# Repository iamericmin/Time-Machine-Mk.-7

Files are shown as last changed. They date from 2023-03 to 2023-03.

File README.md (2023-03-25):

# Time-Machine-Mk.-7
Eagle files for the Time Machine Mk. 7, a DIY digital watch powered by a SAMD21 and an LIR2032 battery.

# Repo map
1. Cutting board: failed projects, simple mockups, etc. that didn't make it to the final product
2. Technical drawings: PDFs of TM7 Rev G, the final production version.
3. TM7 older versions: previous revisions of TM7 I kept just cuz

# This only contains hardware files, I'll be working and uploading software here as well soon!

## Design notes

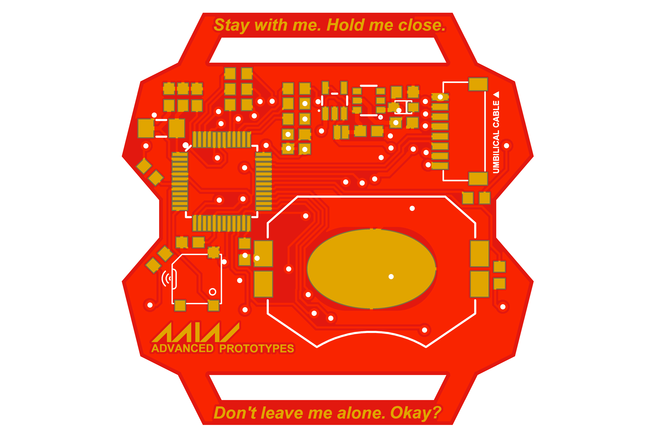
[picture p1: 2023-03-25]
technical drawings/tm7_revG_bottom.png

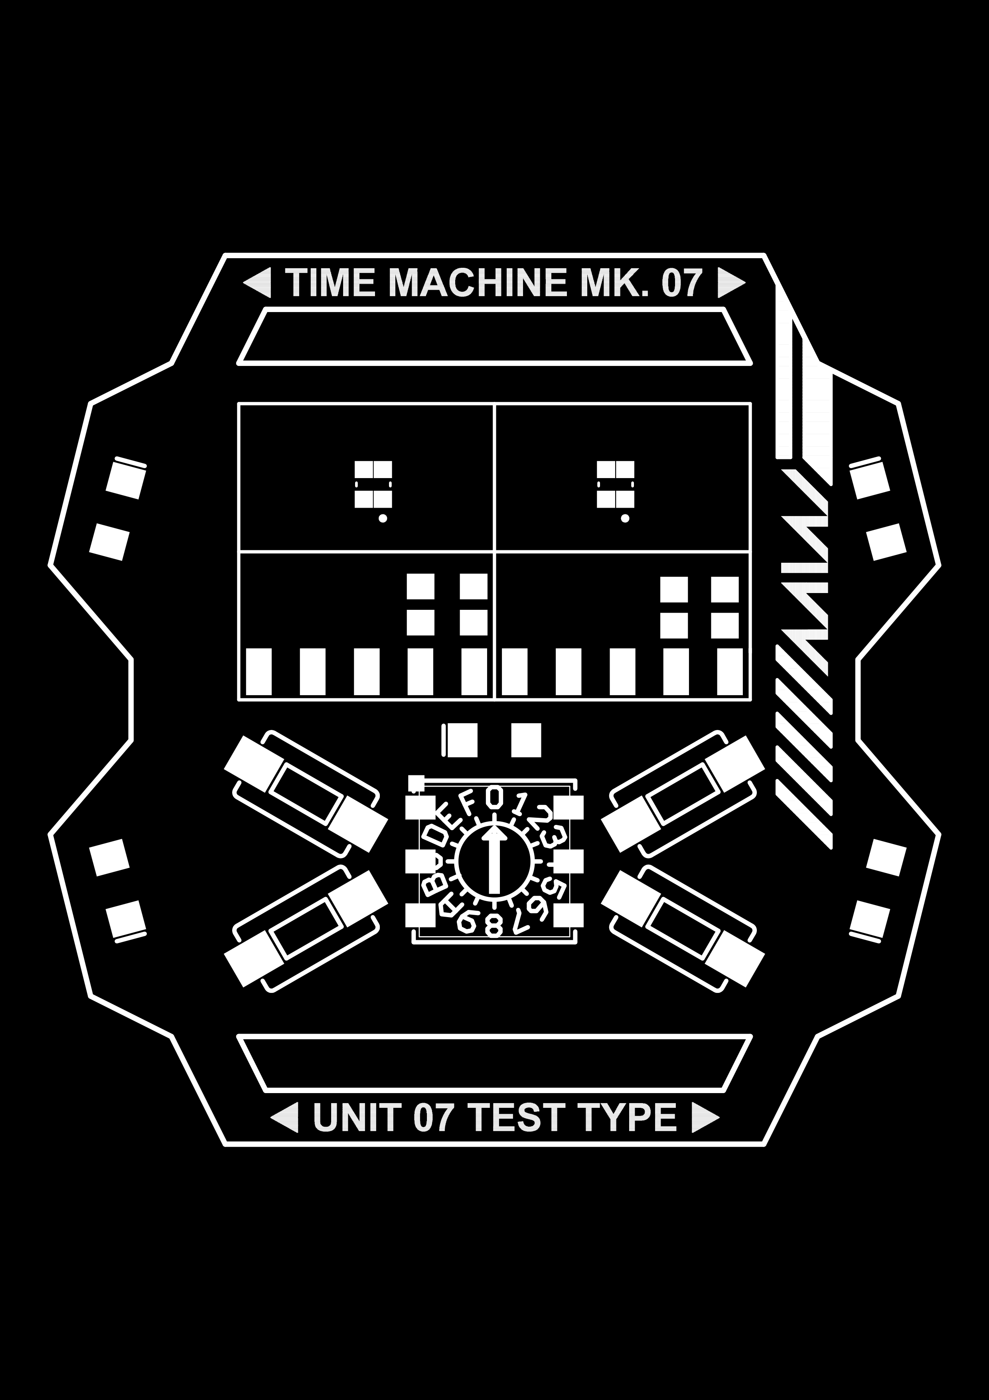
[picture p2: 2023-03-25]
technical drawings/tm7_revG_top_black_inverted.png

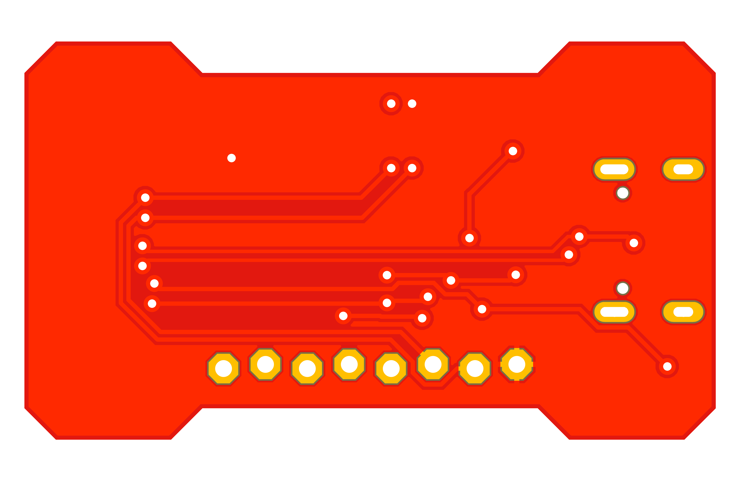
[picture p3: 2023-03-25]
technical drawings/tm7_dock_bottom.png

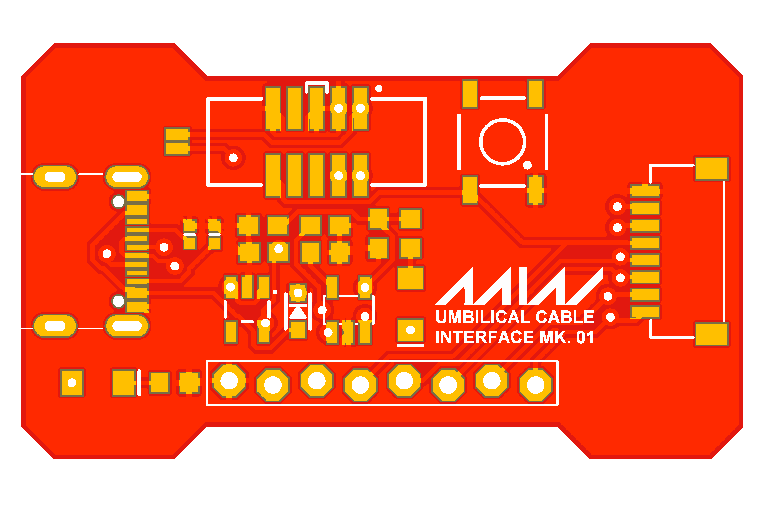
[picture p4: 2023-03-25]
technical drawings/tm7_dock_top.png

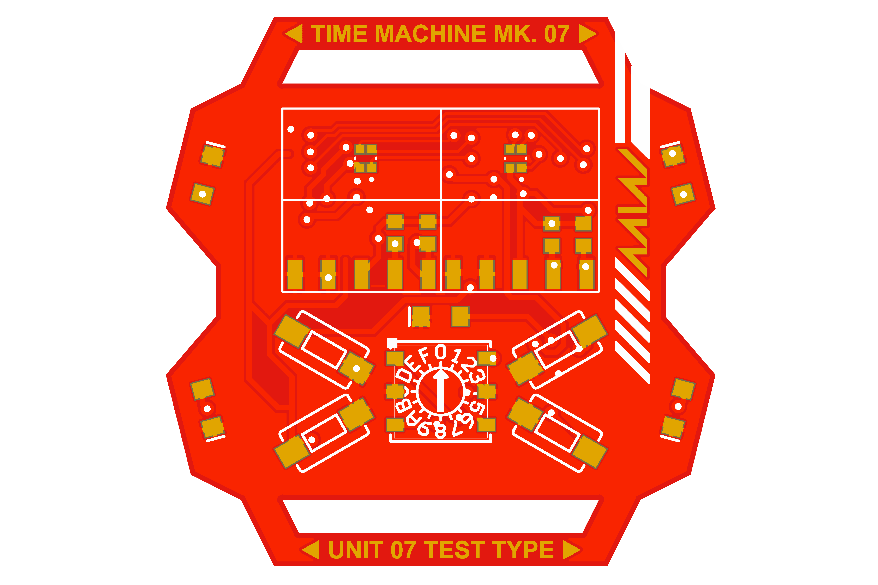
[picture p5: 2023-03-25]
technical drawings/tm7_revG_top.png

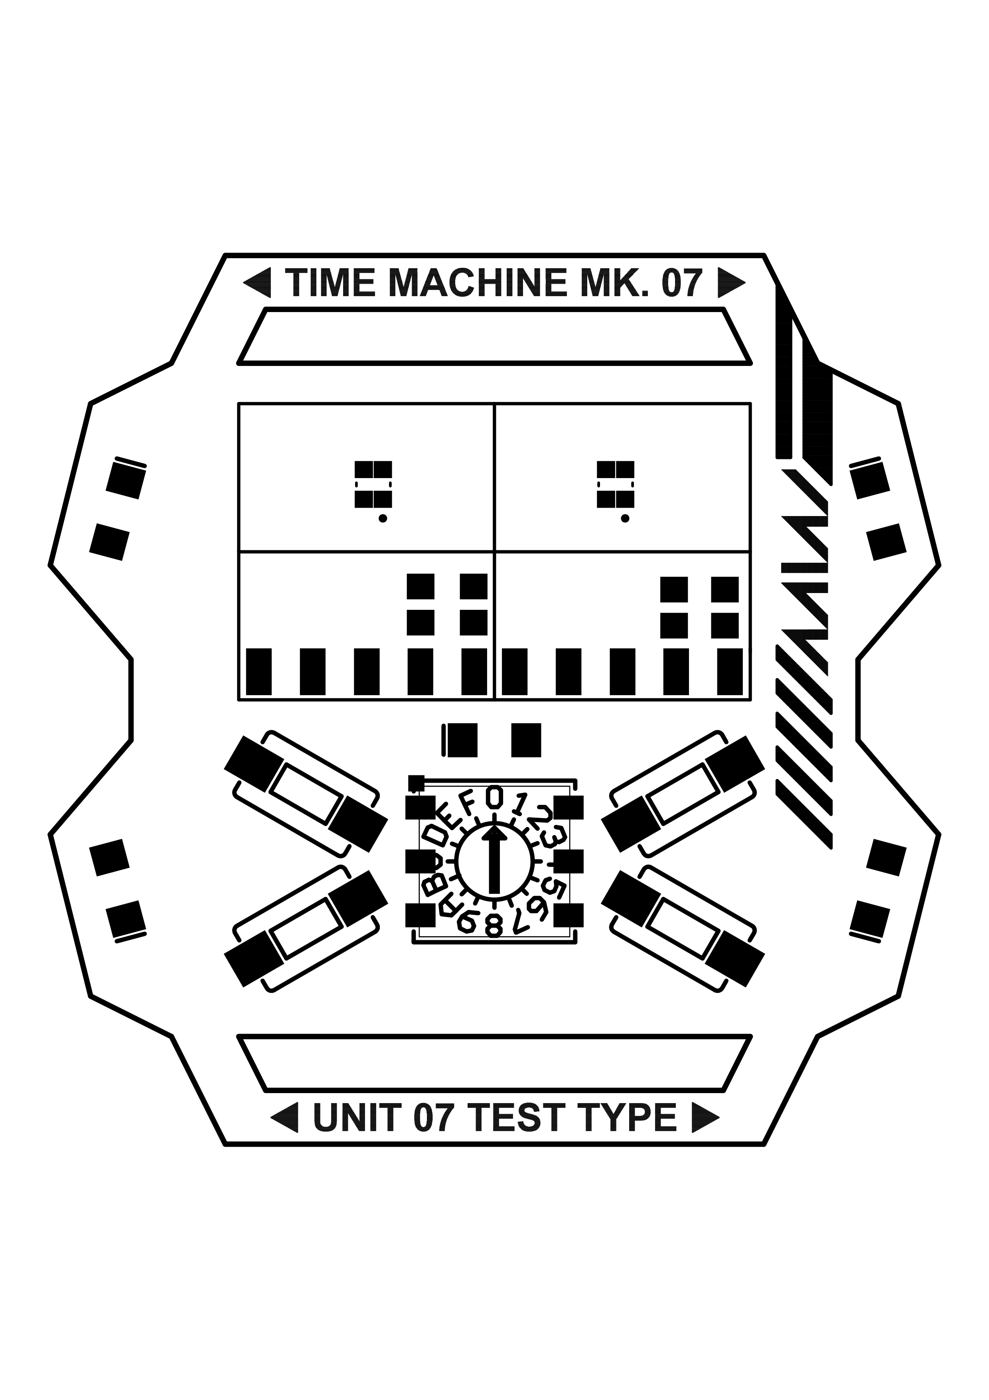
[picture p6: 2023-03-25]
technical drawings/tm7_revG_top_black.png

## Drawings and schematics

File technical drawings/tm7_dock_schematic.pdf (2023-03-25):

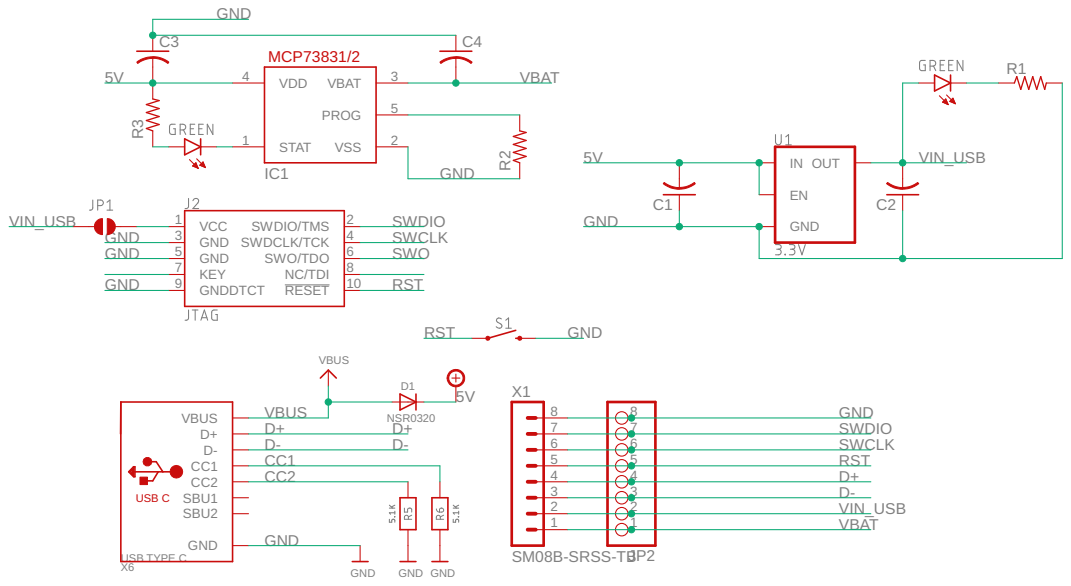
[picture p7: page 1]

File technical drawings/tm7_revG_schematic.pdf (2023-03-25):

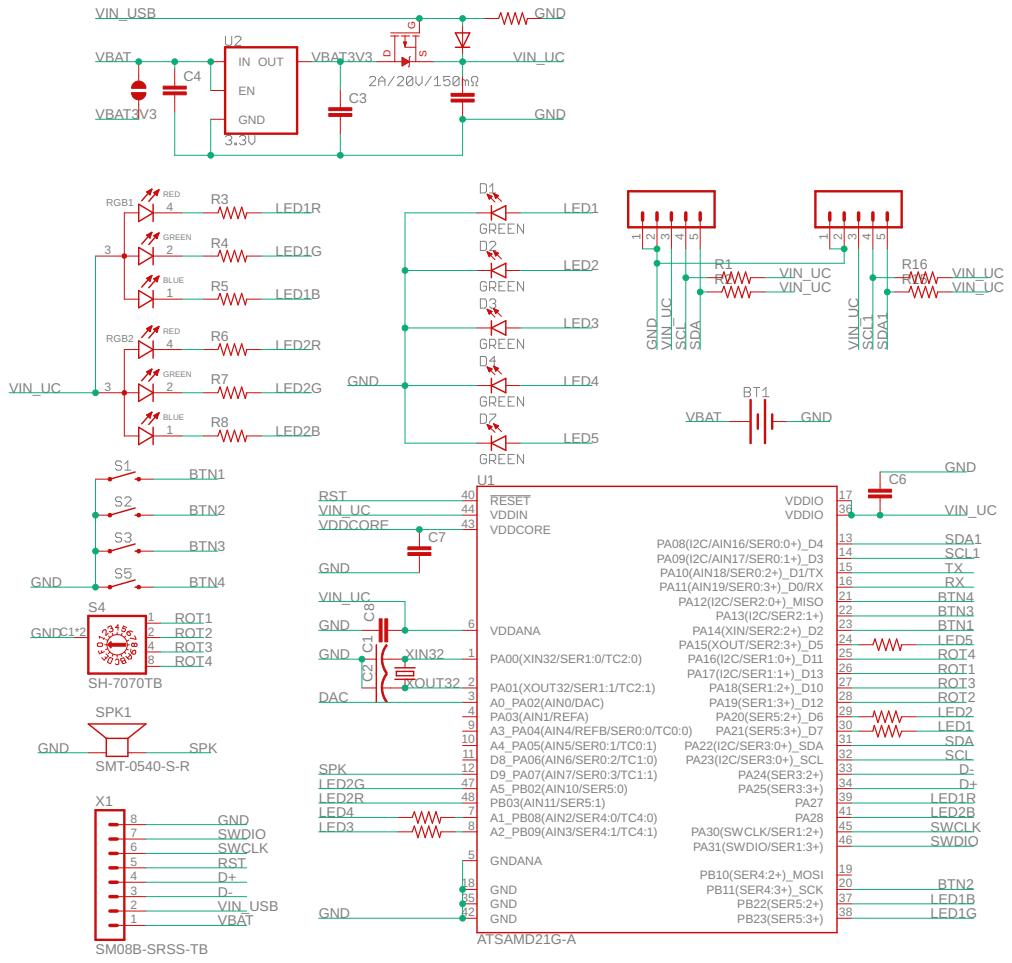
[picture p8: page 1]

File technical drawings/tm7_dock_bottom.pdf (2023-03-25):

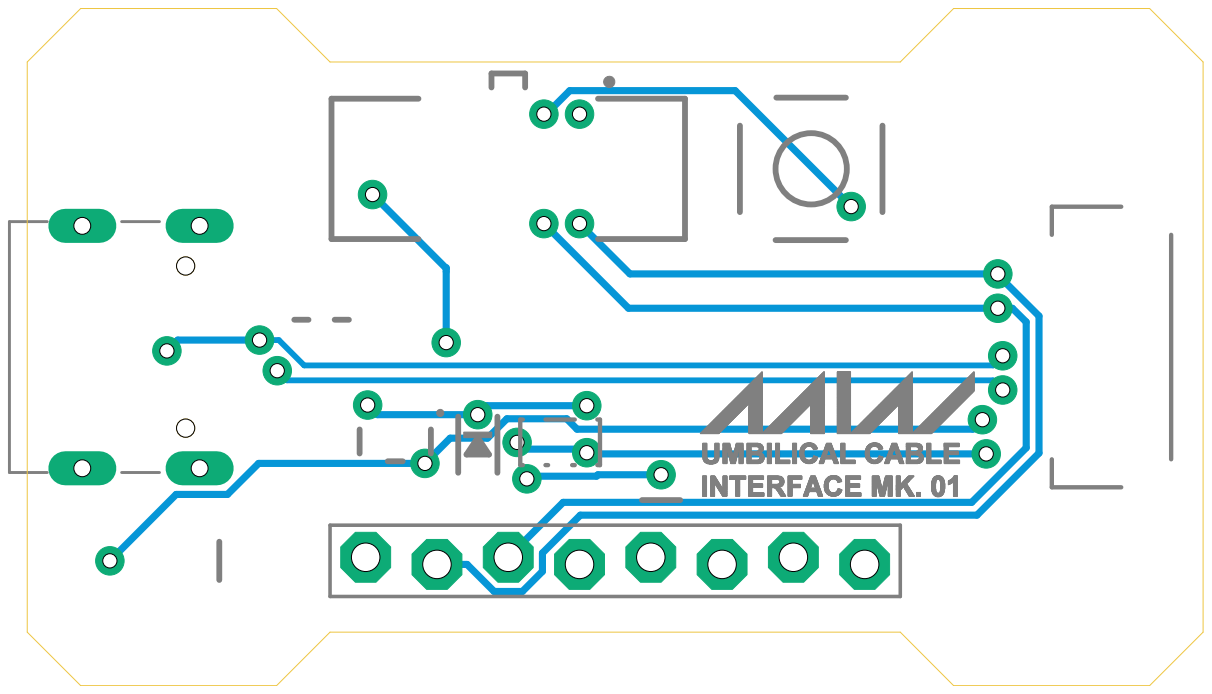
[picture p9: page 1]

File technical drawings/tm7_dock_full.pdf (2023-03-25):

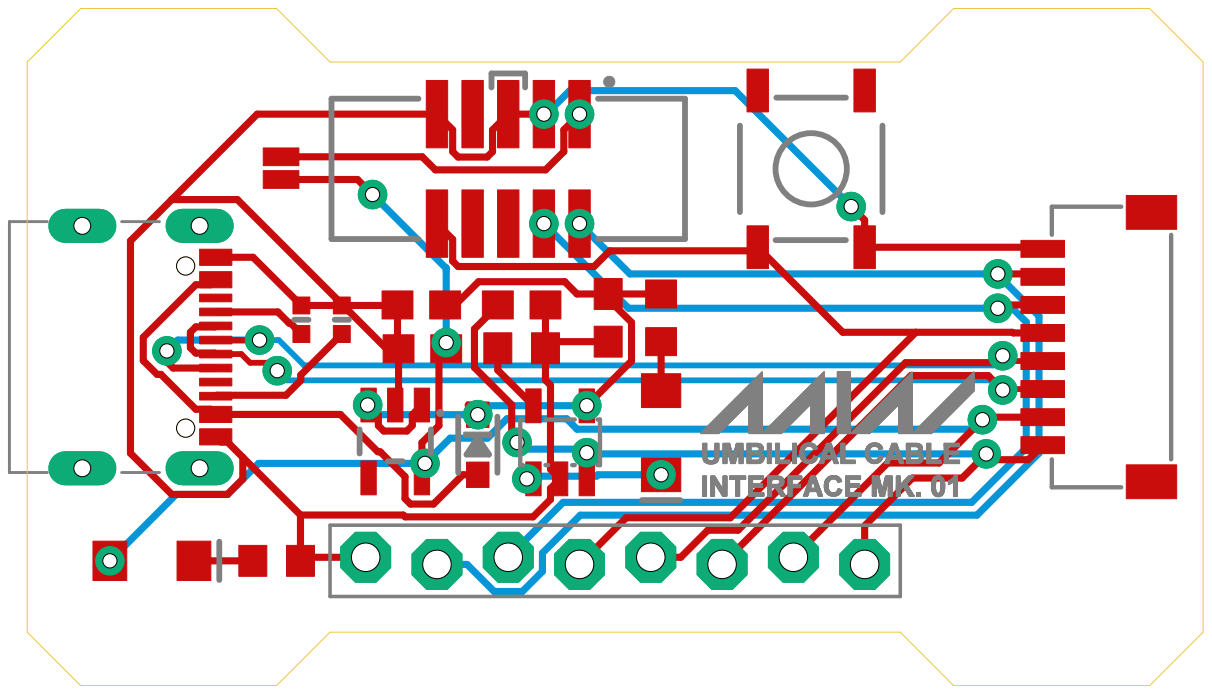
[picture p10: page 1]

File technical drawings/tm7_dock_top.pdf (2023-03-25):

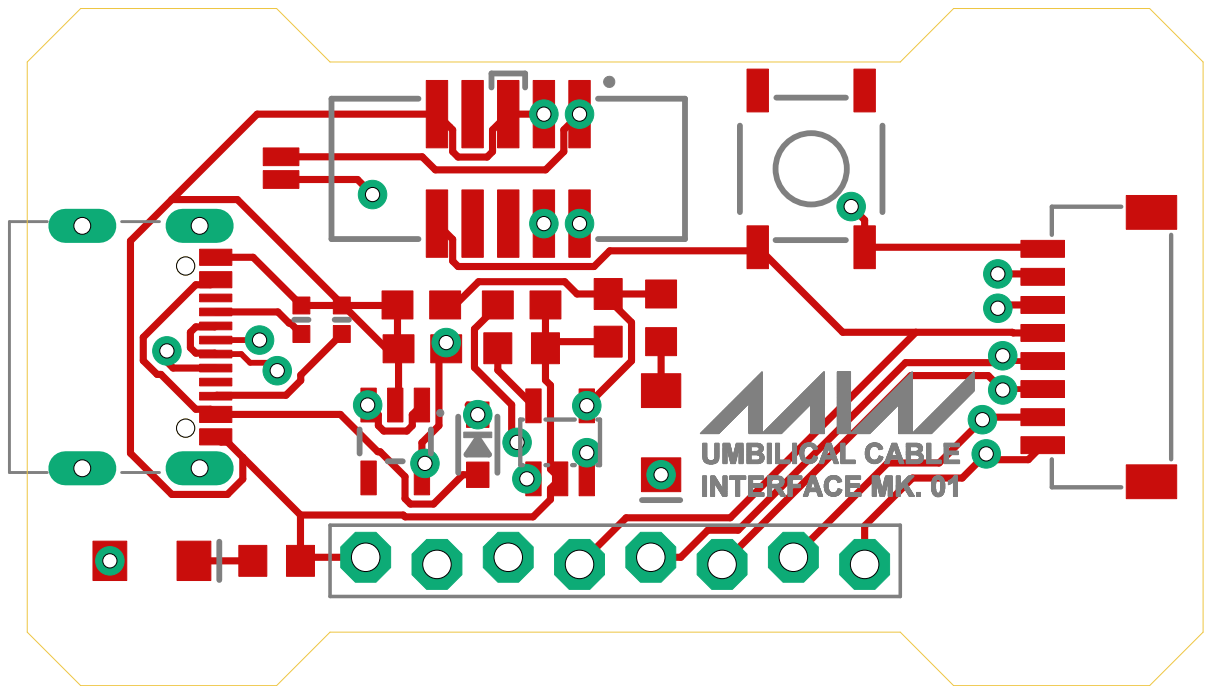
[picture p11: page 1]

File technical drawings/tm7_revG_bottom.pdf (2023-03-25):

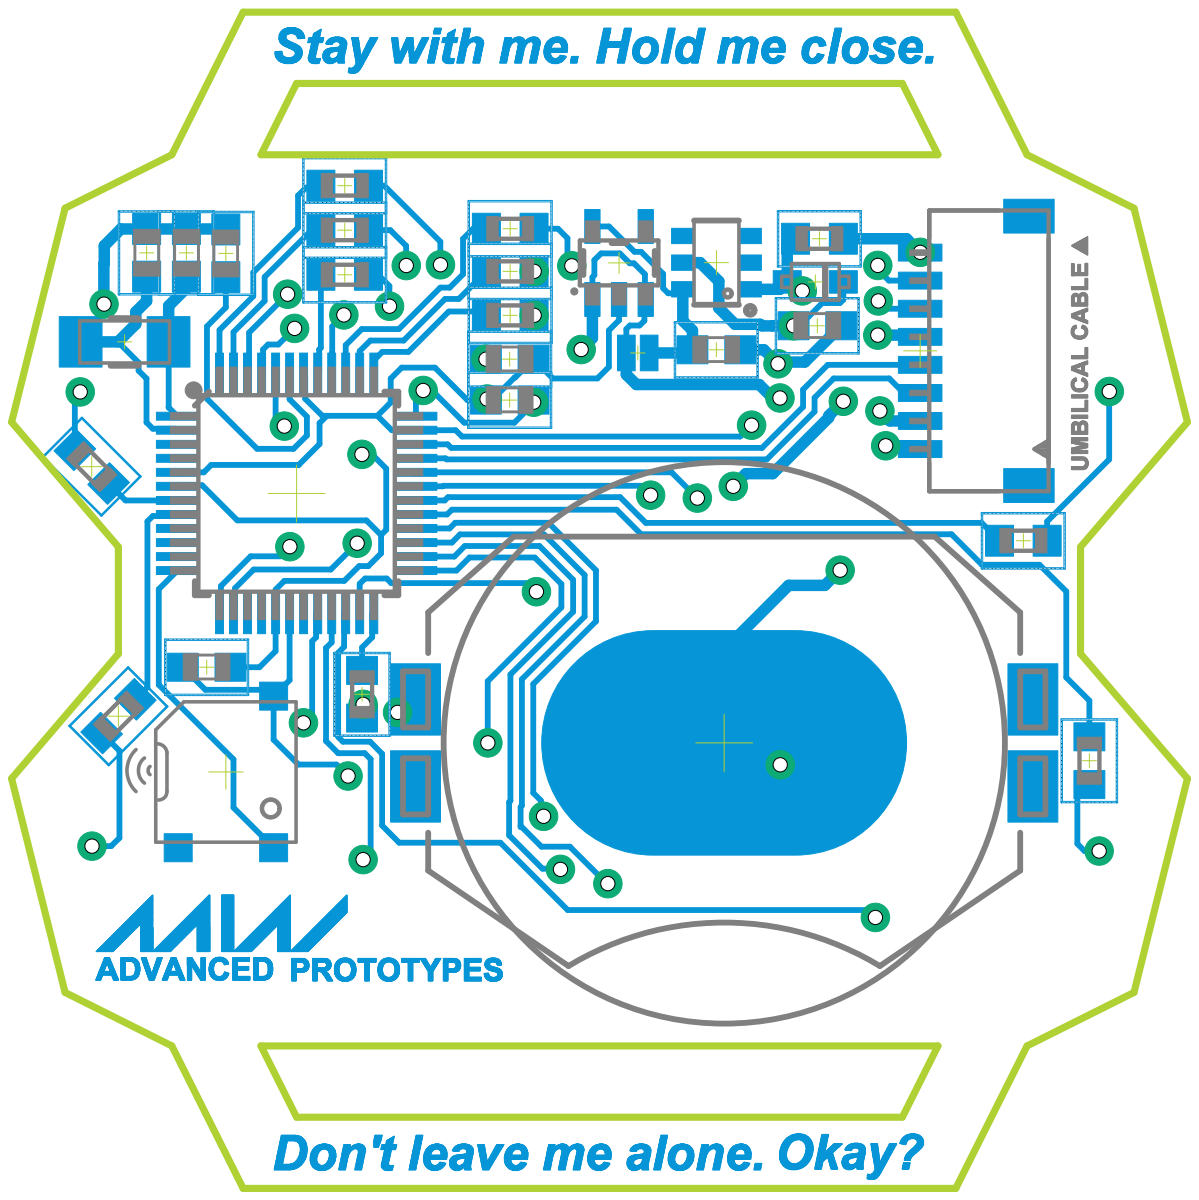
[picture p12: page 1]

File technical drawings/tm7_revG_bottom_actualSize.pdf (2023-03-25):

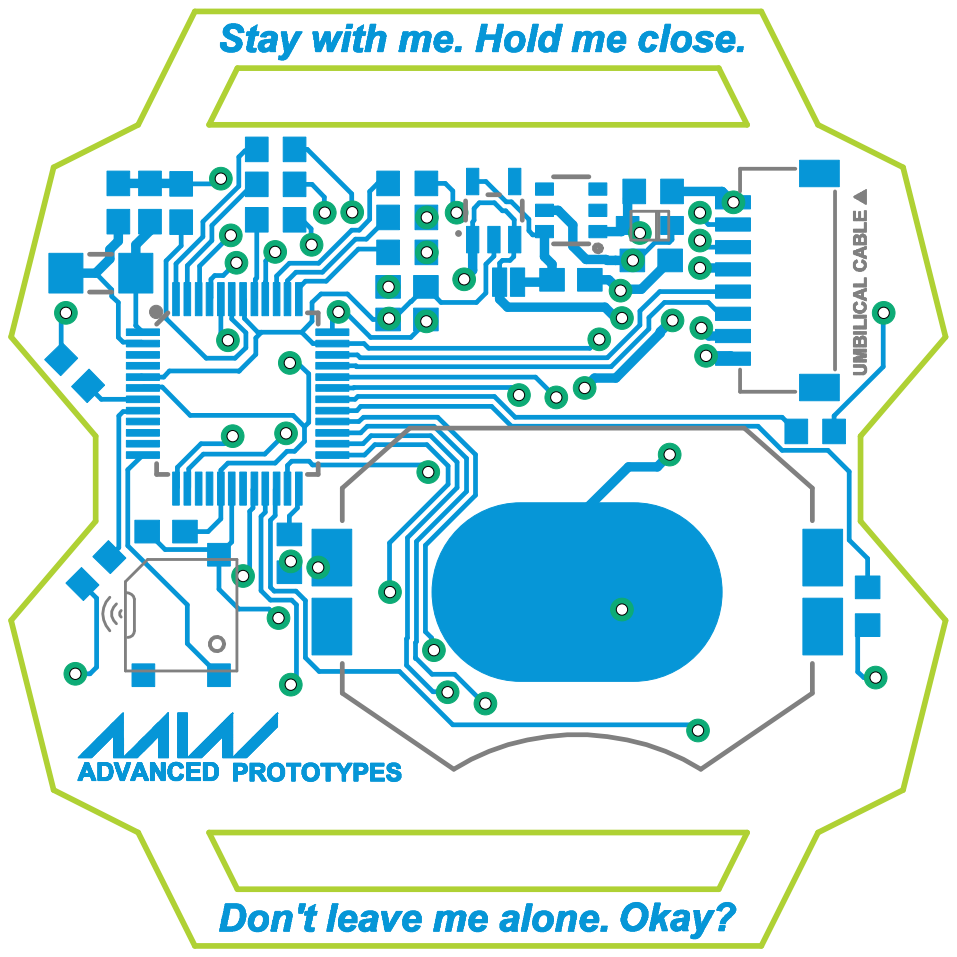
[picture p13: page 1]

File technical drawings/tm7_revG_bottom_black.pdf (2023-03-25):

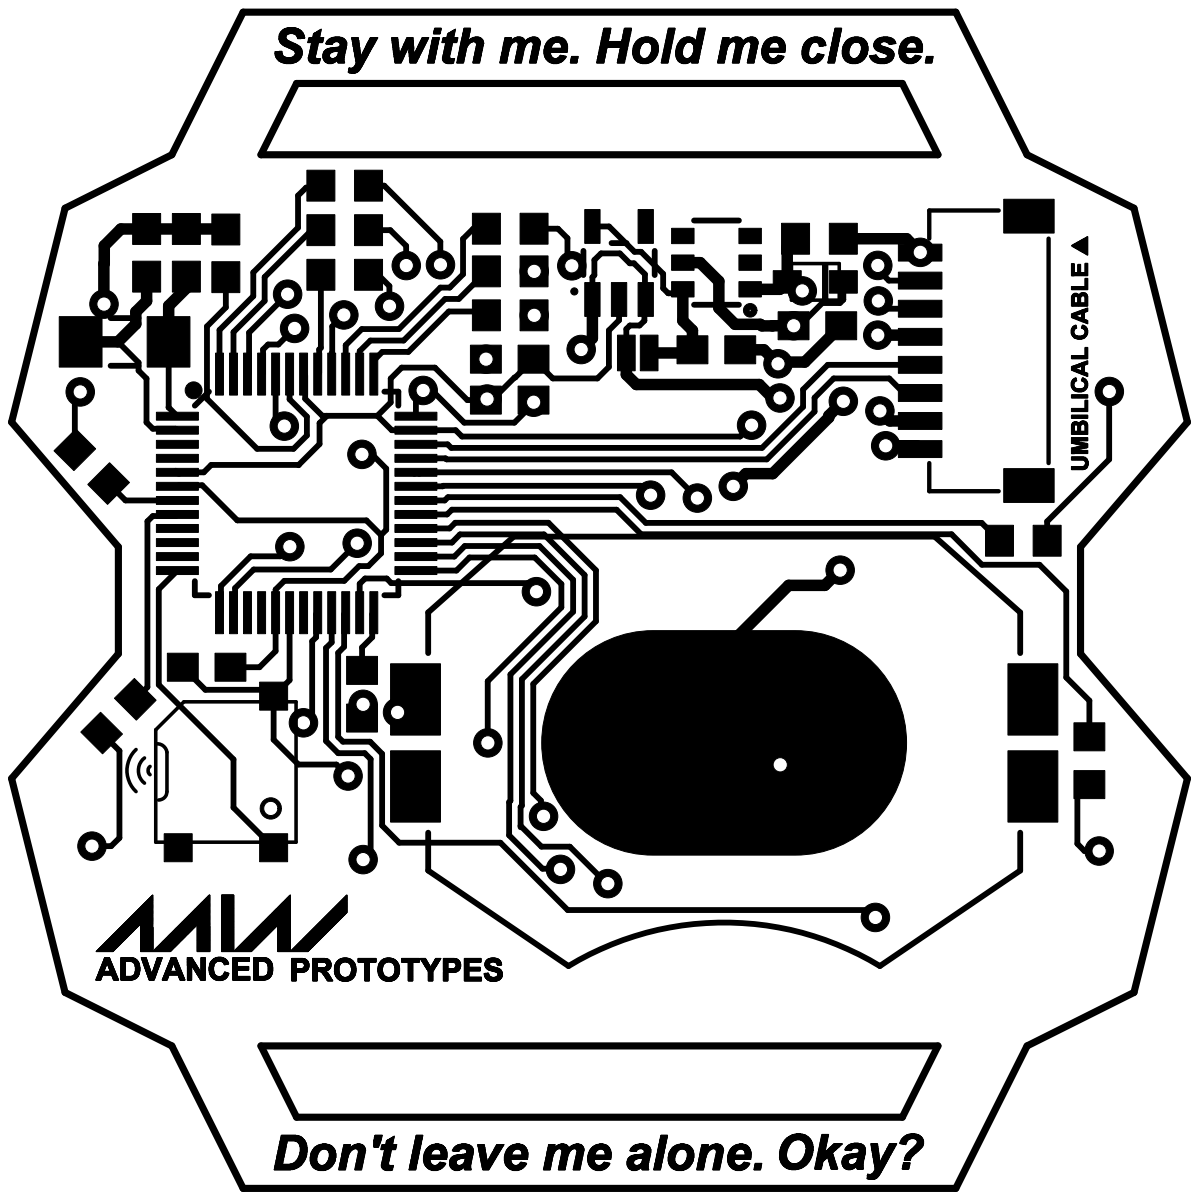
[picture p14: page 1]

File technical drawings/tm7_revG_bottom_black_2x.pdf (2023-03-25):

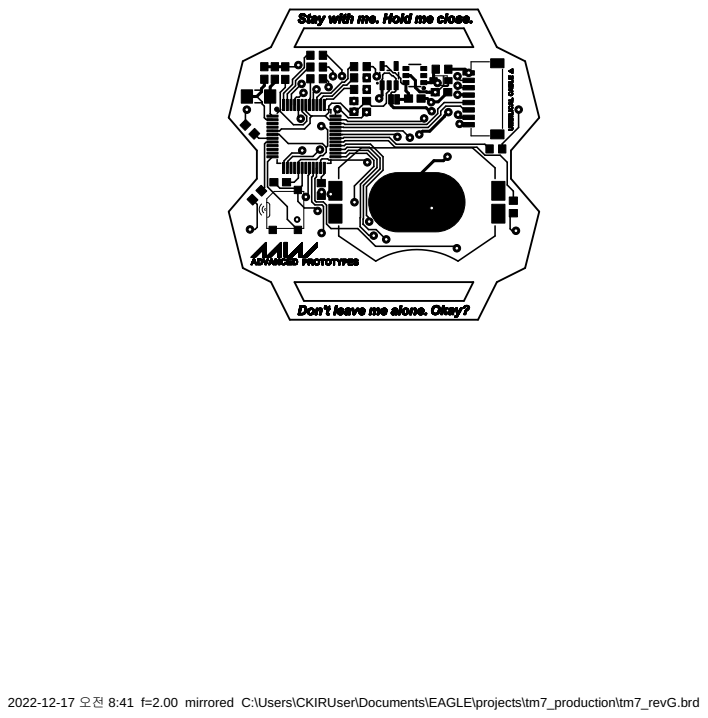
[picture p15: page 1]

2022-12-17 오전 8:41 f=2.00 mirrored C:\Users\CKIRUser\Documents\EAGLE\projects\tm7_production\tm7_revG.brd

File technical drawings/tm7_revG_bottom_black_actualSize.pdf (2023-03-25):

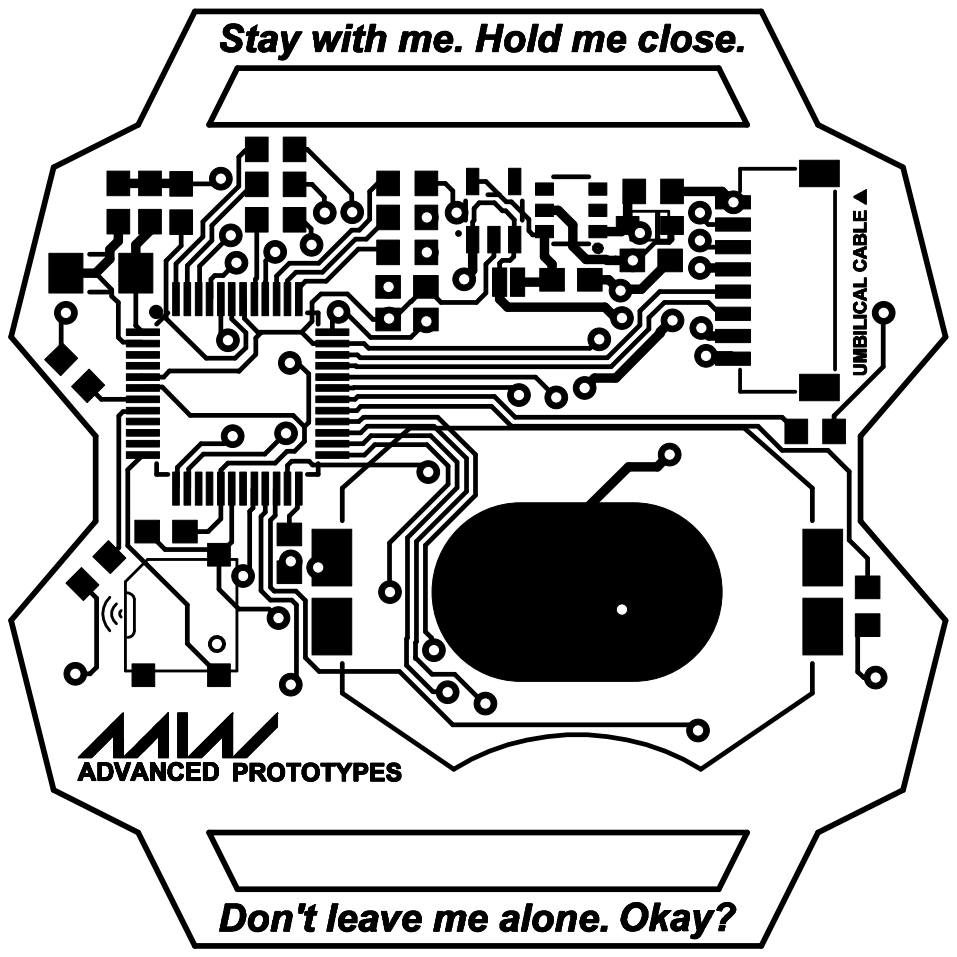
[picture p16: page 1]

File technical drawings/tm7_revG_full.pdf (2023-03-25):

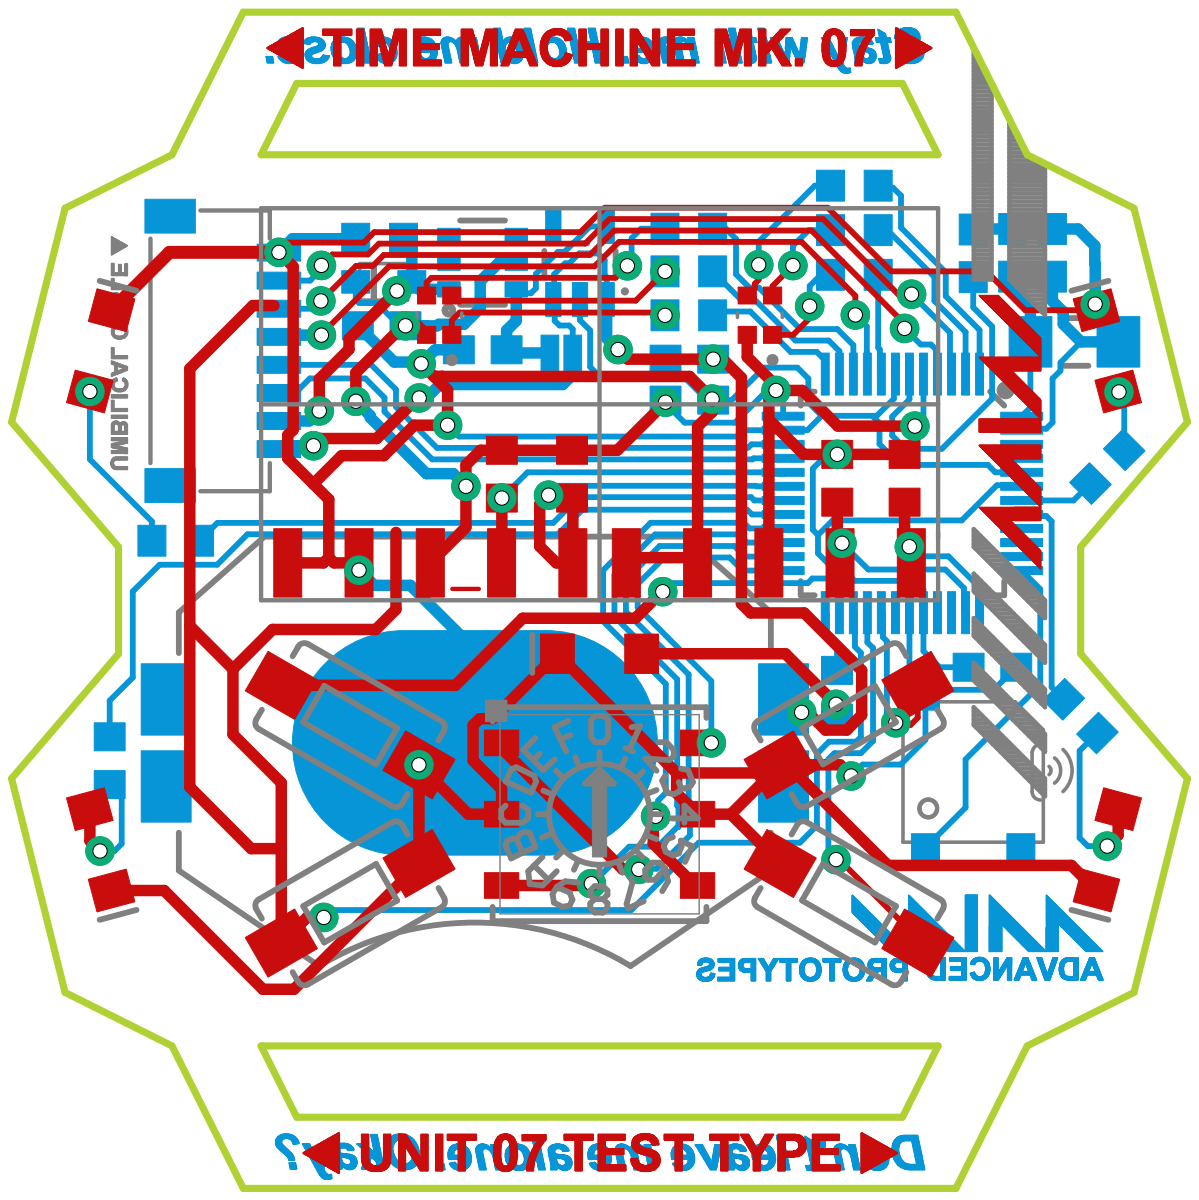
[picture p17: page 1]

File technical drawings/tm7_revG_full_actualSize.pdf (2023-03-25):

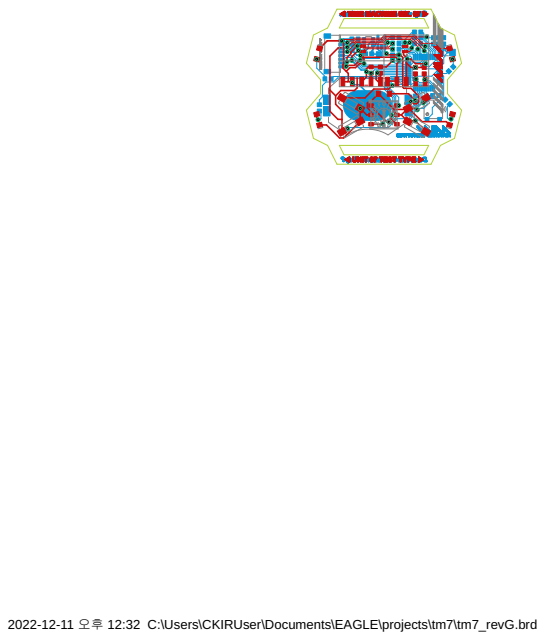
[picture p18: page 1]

2022-12-11 오후 12:32 C:\Users\CKIRUser\Documents\EAGLE\projects\tm7\tm7_revG.brd

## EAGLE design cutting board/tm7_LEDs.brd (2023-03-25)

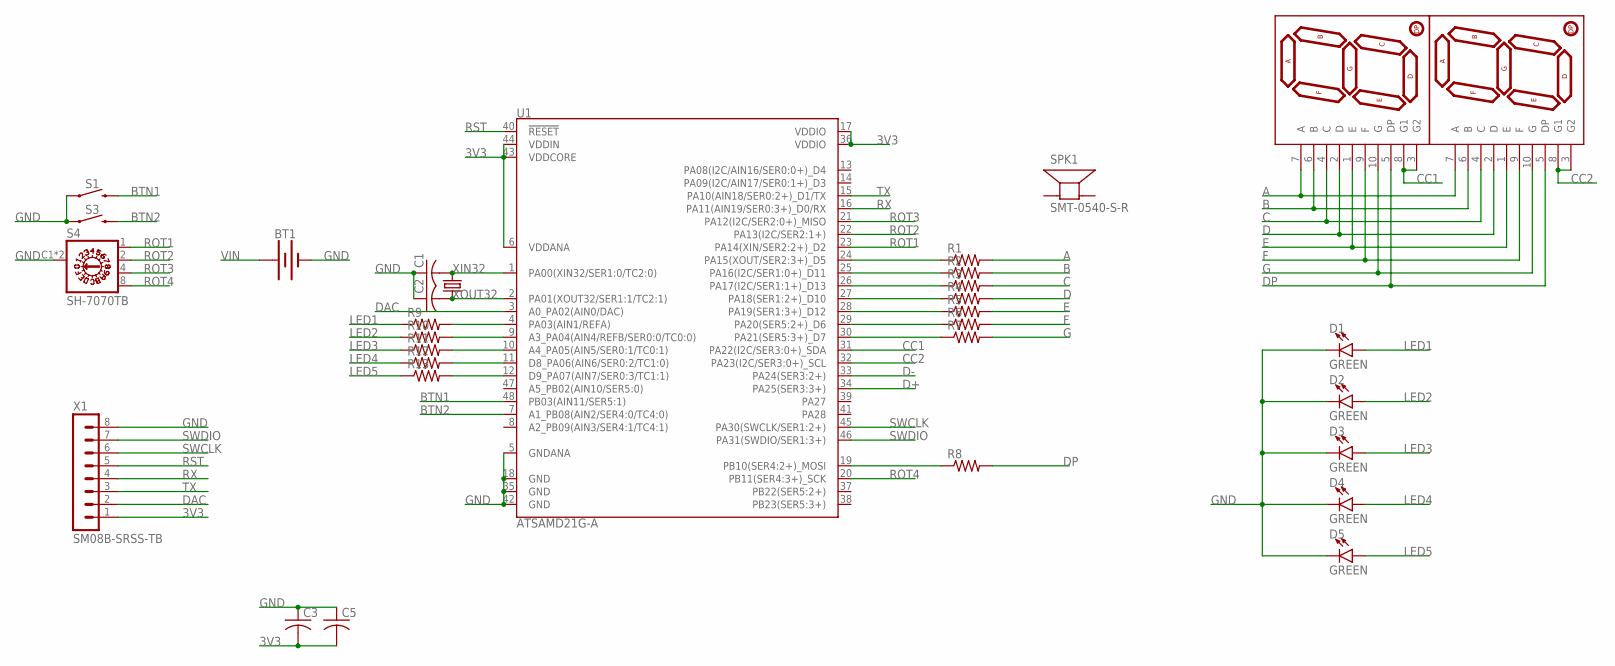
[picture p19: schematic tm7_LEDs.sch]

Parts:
BT1: BATTERY-20MM_SMD_4LEGS_OVERPASTE_INNER; BATTCON_20MM_4LEGS_OVERPASTE_INNER
C1, C2, C3, C5: C-USC0603; C0603
D1, D2, D3, D4, D5: GREEN; LED-1206
R1, R2, R3, R4, R5, R6, R7, R8, R9, R10, R11, R12, R13: R-US_R0603; R0603
S1, S3: MOMENTARY-SWITCH-SPST-SMD-6.2MM-TALL; TACTILE_SWITCH_SMD_6.2MM_TALL
S4: SH-7070TB; SH-7070B
SPK1: SMT-0540-S-R
U1: ATSAMD21G-A; TQFP-48
U$2, U$3: 7-SEGMENT-DISPLAY-1"-RED; 7-SEGMENT-SMD
X1: SM08B-SRSS-TB
Y1: 32.768kHz; CRYSTAL-SMD-3.2X1.5MM

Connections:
3V3: C3.2, C5.2, U1.6 (VDDANA), U1.17 (VDDIO), U1.36 (VDDIO), U1.43 (VDDCORE), U1.44 (VDDIN), X1.1
A: R1.2, U$2.7 (A), U$3.7 (A)
B: R2.2, U$2.6 (B), U$3.6 (B)
BTN1: S1.B2 (2), U1.48 (PB03(AIN11/SER5:1))
BTN2: S3.B2 (2), U1.7 (A1_PB08(AIN2/SER4:0/TC4:0))
C: R3.2, U$2.4 (C), U$3.4 (C)
CC1: U1.31 (PA22(I2C/SER3:0+)_SDA), U$2.3 (G2), U$2.8 (G1)
CC2: U1.32 (PA23(I2C/SER3:0+)_SCL), U$3.3 (G2), U$3.8 (G1)
D: R4.2, U$2.2 (D), U$3.2 (D)
D+: U1.34 (PA25(SER3:3+))
D-: U1.33 (PA24(SER3:2+))
DAC: U1.3 (A0_PA02(AIN0/DAC)), X1.2
DP: R8.2, U$2.5 (DP), U$3.5 (DP)
E: R5.2, U$2.1 (E), U$3.1 (E)
F: R6.2, U$2.9 (F), U$3.9 (F)
G: R7.2, U$2.10 (G), U$3.10 (G)
GND: BT1.2 (-), C1.1, C2.1, C3.1, C5.1, D1.C, D2.C, D3.C, D4.C, D5.C, S1.A2 (1), S3.A2 (1), S4.C1 (C), S4.C2 (C), U1.5 (GNDANA), U1.18 (GND), U1.35 (GND), U1.42 (GND), X1.8
LED1: D1.A, R9.1
LED2: D2.A, R10.1
LED3: D3.A, R11.1
LED4: D4.A, R12.1
LED5: D5.A, R13.1
unnamed: R1.1, U1.24 (PA15(XOUT/SER2:3+)_D5)
unnamed: R2.1, U1.25 (PA16(I2C/SER1:0+)_D11)
unnamed: R3.1, U1.26 (PA17(I2C/SER1:1+)_D13)
unnamed: R4.1, U1.27 (PA18(SER1:2+)_D10)
unnamed: R5.1, U1.28 (PA19(SER1:3+)_D12)
unnamed: R7.1, U1.30 (PA21(SER5:3+)_D7)
unnamed: R6.1, U1.29 (PA20(SER5:2+)_D6)
unnamed: R8.1, U1.19 (PB10(SER4:2+)_MOSI)
unnamed: R9.2, U1.4 (PA03(AIN1/REFA))
unnamed: R10.2, U1.9 (A3_PA04(AIN4/REFB/SER0:0/TC0:0))
unnamed: R11.2, U1.10 (A4_PA05(AIN5/SER0:1/TC0:1))
unnamed: R12.2, U1.11 (D8_PA06(AIN6/SER0:2/TC1:0))
unnamed: R13.2, U1.12 (D9_PA07(AIN7/SER0:3/TC1:1))
ROT1: S4.1, U1.23 (PA14(XIN/SER2:2+)_D2)
ROT2: S4.2, U1.22 (PA13(I2C/SER2:1+))
ROT3: S4.4, U1.21 (PA12(I2C/SER2:0+)_MISO)
ROT4: S4.8, U1.20 (PB11(SER4:3+)_SCK)
RST: U1.40 (!RESET!), X1.5
RX: U1.16 (PA11(AIN19/SER0:3+)_D0/RX), X1.4
SWCLK: U1.45 (PA30(SWCLK/SER1:2+)), X1.6
SWDIO: U1.46 (PA31(SWDIO/SER1:3+)), X1.7
TX: U1.15 (PA10(AIN18/SER0:2+)_D1/TX), X1.3
VIN: BT1.1 (+)
XIN32: C1.2, U1.1 (PA00(XIN32/SER1:0/TC2:0)), Y1.P$2 (2)
XOUT32: C2.2, U1.2 (PA01(XOUT32/SER1:1/TC2:1)), Y1.P$1 (1)

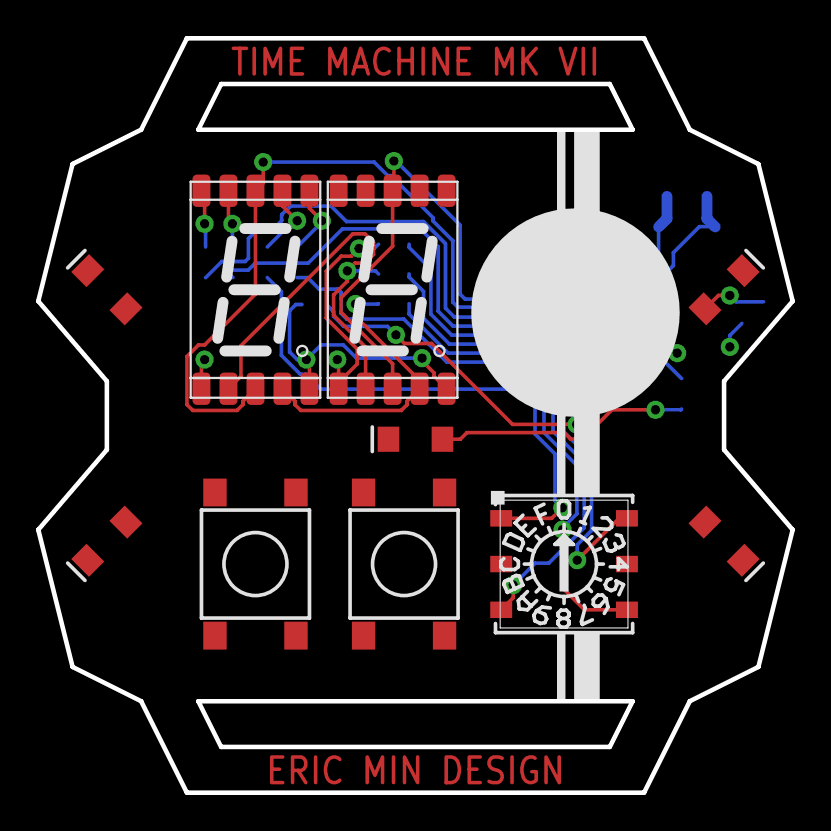
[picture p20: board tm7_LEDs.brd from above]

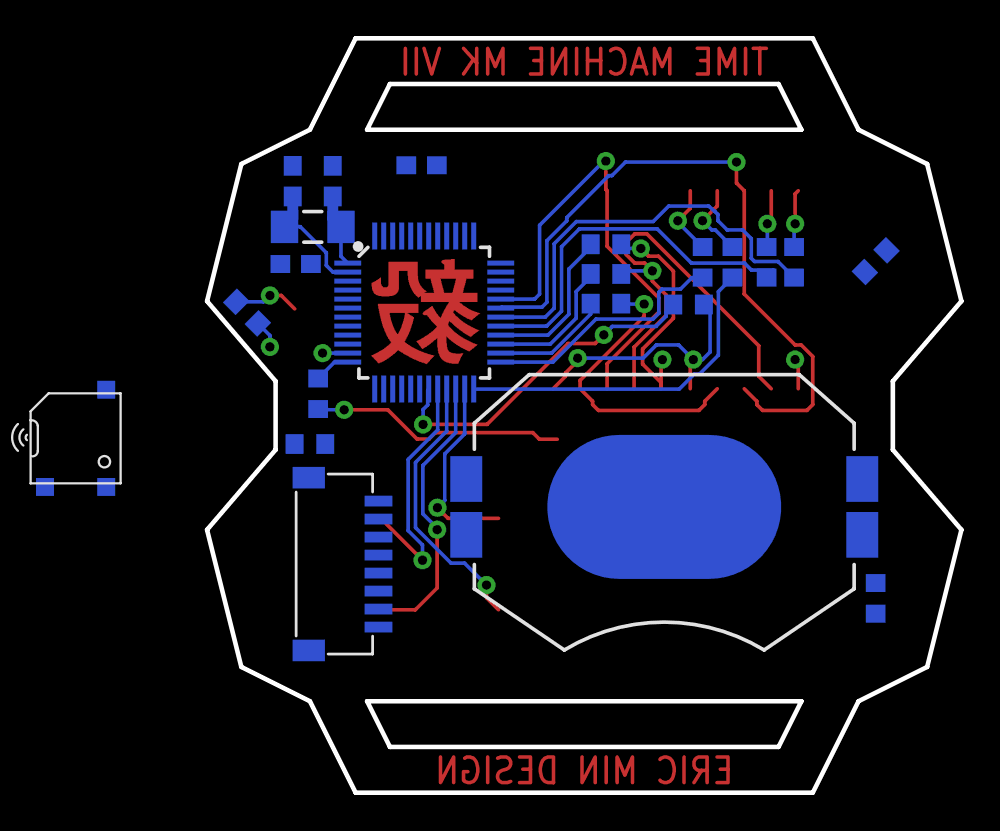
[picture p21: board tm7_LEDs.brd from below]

Board: 4 copper layers, 41.9 x 41.9 mm, 32 parts (22 on the bottom side), 44 nets.

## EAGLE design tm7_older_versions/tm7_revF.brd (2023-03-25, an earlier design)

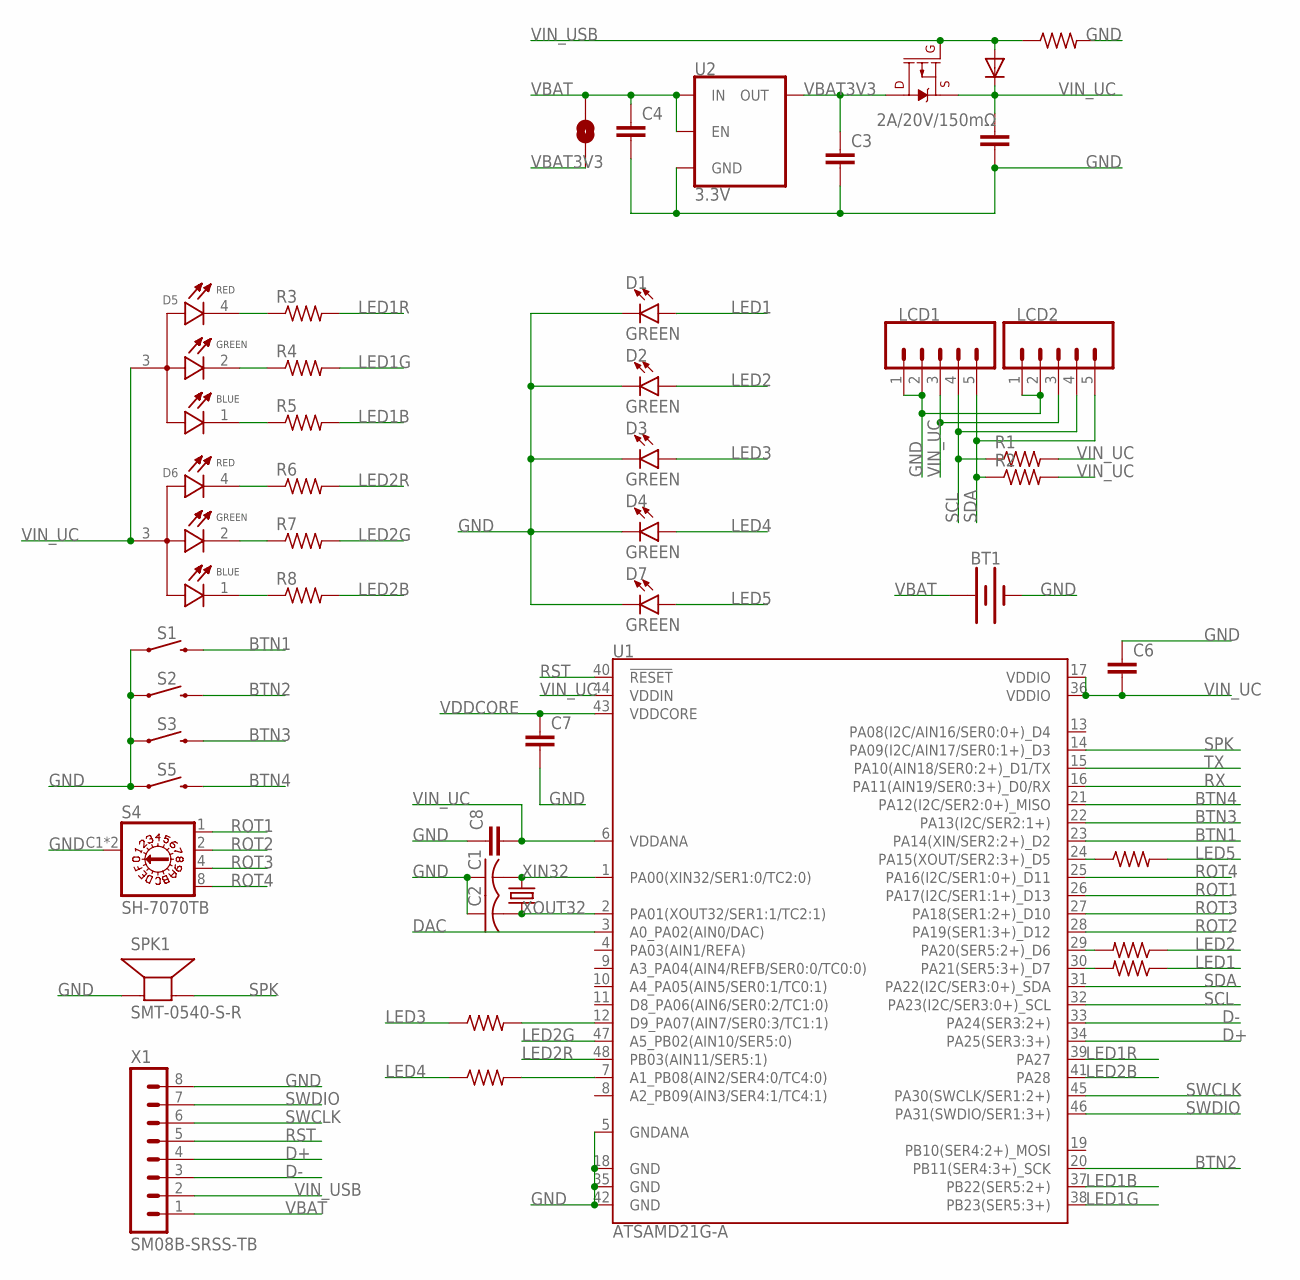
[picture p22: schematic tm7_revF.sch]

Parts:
BT1: BATTERY-20MM_SMD_4LEGS_OVERPASTE_INNER; BATTCON_20MM_4LEGS_OVERPASTE_INNER
C1, C2: C-USC0603; C0603
C3, C4, C6, C7, C8, C9: C-EUC0603; C0603
D1, D2, D3, D4, D7: GREEN; LED-1206
D5, D6: EAST1616RGBA3; LED_EAST1616RGBA3
D8: DIODESOD-323F; SOD-323F
JP1: JUMPER-SMT_2_NO_NO-SILK; SMT-JUMPER_2_NO_NO-SILK
LCD1, LCD2: CONN_05VERT_FEMALE_HEADER; 1X05_SMD_VERTICAL_COMBO
Q1: 2A/20V/150mΩ; SOT26
R1, R2, R3, R4, R5, R6, R7, R8, R9, R10, R11, R12, R13, R14: R-US_R0603; R0603
S1, S2, S3, S5: MOMENTARY-SWITCH-SPST-SMD-6.0X3.5MM; TACTILE_SWITCH_SMD_6.0X3.5MM
S4: SH-7070TB; SH-7070B
SPK1: SMT-0540-S-R
U1: ATSAMD21G-A; TQFP-48
U2: 3.3V; SOT23-5
X1: SM08B-SRSS-TB
Y1: 32.768kHz; CRYSTAL-SMD-3.2X1.5MM

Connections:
BTN1: S1.2, U1.23 (PA14(XIN/SER2:2+)_D2)
BTN2: S2.2, U1.20 (PB11(SER4:3+)_SCK)
BTN3: S3.2, U1.22 (PA13(I2C/SER2:1+))
BTN4: S5.2, U1.21 (PA12(I2C/SER2:0+)_MISO)
D+: U1.34 (PA25(SER3:3+)), X1.4
D-: U1.33 (PA24(SER3:2+)), X1.3
DAC: U1.3 (A0_PA02(AIN0/DAC))
GND: BT1.2 (-), C1.1, C2.1, C3.2, C4.2, C6.1, C7.2, C8.1, C9.2, D1.C, D2.C, D3.C, D4.C, D7.C, LCD1.1, LCD1.2, LCD2.1, LCD2.2, R14.2, S1.1, S2.1, S3.1, S4.C1 (C), S4.C2 (C), S5.1, SPK1.- (+), U1.5 (GNDANA), U1.18 (GND), U1.35 (GND), U1.42 (GND), U2.2 (GND), X1.8
LED1: D1.A, R9.1
LED1B: R5.2, U1.37 (PB22(SER5:2+))
LED1G: R4.2, U1.38 (PB23(SER5:3+))
LED1R: R3.2, U1.39 (PA27)
LED2: D2.A, R10.1
LED2B: R8.2, U1.41 (PA28)
LED2G: R7.2, U1.47 (A5_PB02(AIN10/SER5:0))
LED2R: R6.2, U1.48 (PB03(AIN11/SER5:1))
LED3: D3.A, R11.1
LED4: D4.A, R12.1
LED5: D7.A, R13.2
unnamed: R12.2, U1.7 (A1_PB08(AIN2/SER4:0/TC4:0))
unnamed: R11.2, U1.12 (D9_PA07(AIN7/SER0:3/TC1:1))
unnamed: R9.2, U1.30 (PA21(SER5:3+)_D7)
unnamed: R10.2, U1.29 (PA20(SER5:2+)_D6)
unnamed: D5.4 (R_C), R3.1
unnamed: D5.2 (G_C), R4.1
unnamed: D5.1 (B_C), R5.1
unnamed: D6.4 (R_C), R6.1
unnamed: D6.2 (G_C), R7.1
unnamed: D6.1 (B_C), R8.1
unnamed: R13.1, U1.24 (PA15(XOUT/SER2:3+)_D5)
ROT1: S4.1, U1.26 (PA17(I2C/SER1:1+)_D13)
ROT2: S4.2, U1.28 (PA19(SER1:3+)_D12)
ROT3: S4.4, U1.27 (PA18(SER1:2+)_D10)
ROT4: S4.8, U1.25 (PA16(I2C/SER1:0+)_D11)
RST: U1.40 (!RESET!), X1.5
RX: U1.16 (PA11(AIN19/SER0:3+)_D0/RX)
SCL: LCD1.4, LCD2.4, R1.1, U1.32 (PA23(I2C/SER3:0+)_SCL)
SDA: LCD1.5, LCD2.5, R2.1, U1.31 (PA22(I2C/SER3:0+)_SDA)
SPK: SPK1.+ (-), U1.14 (PA09(I2C/AIN17/SER0:1+)_D3)
SWCLK: U1.45 (PA30(SWCLK/SER1:2+)), X1.6
SWDIO: U1.46 (PA31(SWDIO/SER1:3+)), X1.7
TX: U1.15 (PA10(AIN18/SER0:2+)_D1/TX)
VBAT: BT1.1 (+), C4.1, JP1.2, U2.1 (IN), U2.3 (EN), X1.1
VBAT3V3: C3.1, JP1.1, Q1.D1 (D), U2.5 (OUT)
VDDCORE: C7.1, U1.43 (VDDCORE)
VIN_UC: C6.2, C8.2, C9.1, D5.3 (A), D6.3 (A), D8.C, LCD1.3, LCD2.3, Q1.S1 (S), R1.2, R2.2, U1.6 (VDDANA), U1.17 (VDDIO), U1.36 (VDDIO), U1.44 (VDDIN)
VIN_USB: D8.A, Q1.G1 (G), R14.1, X1.2
XIN32: C1.2, U1.1 (PA00(XIN32/SER1:0/TC2:0)), Y1.P$2 (2)
XOUT32: C2.2, U1.2 (PA01(XOUT32/SER1:1/TC2:1)), Y1.P$1 (1)

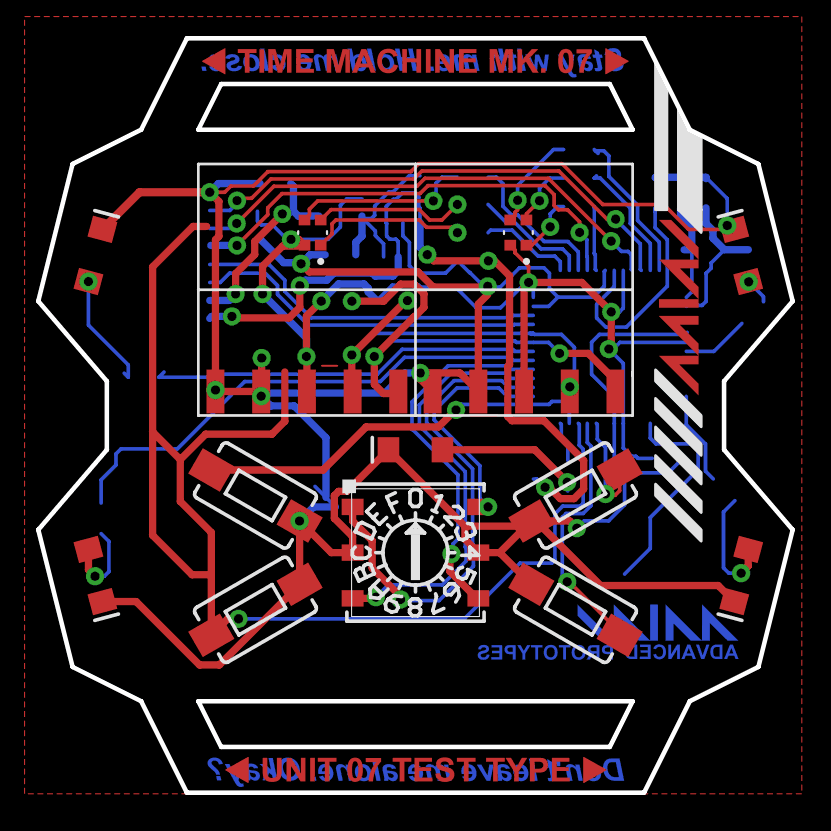
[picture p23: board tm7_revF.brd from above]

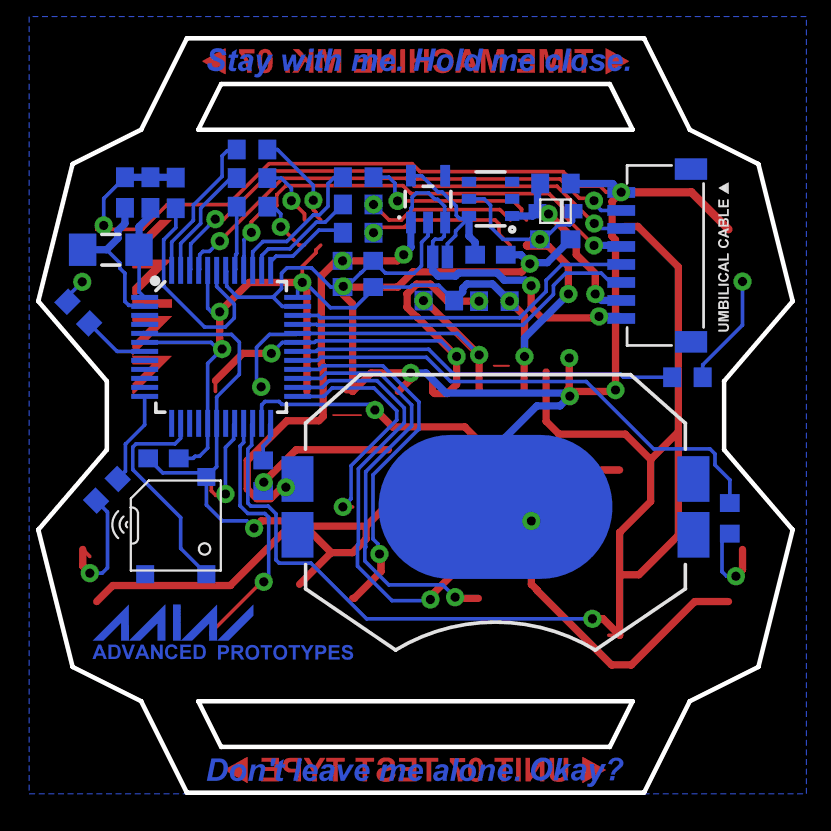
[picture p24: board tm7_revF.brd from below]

Board: 2 copper layers, 41.9 x 41.9 mm, 45 parts (31 on the bottom side), 46 nets.

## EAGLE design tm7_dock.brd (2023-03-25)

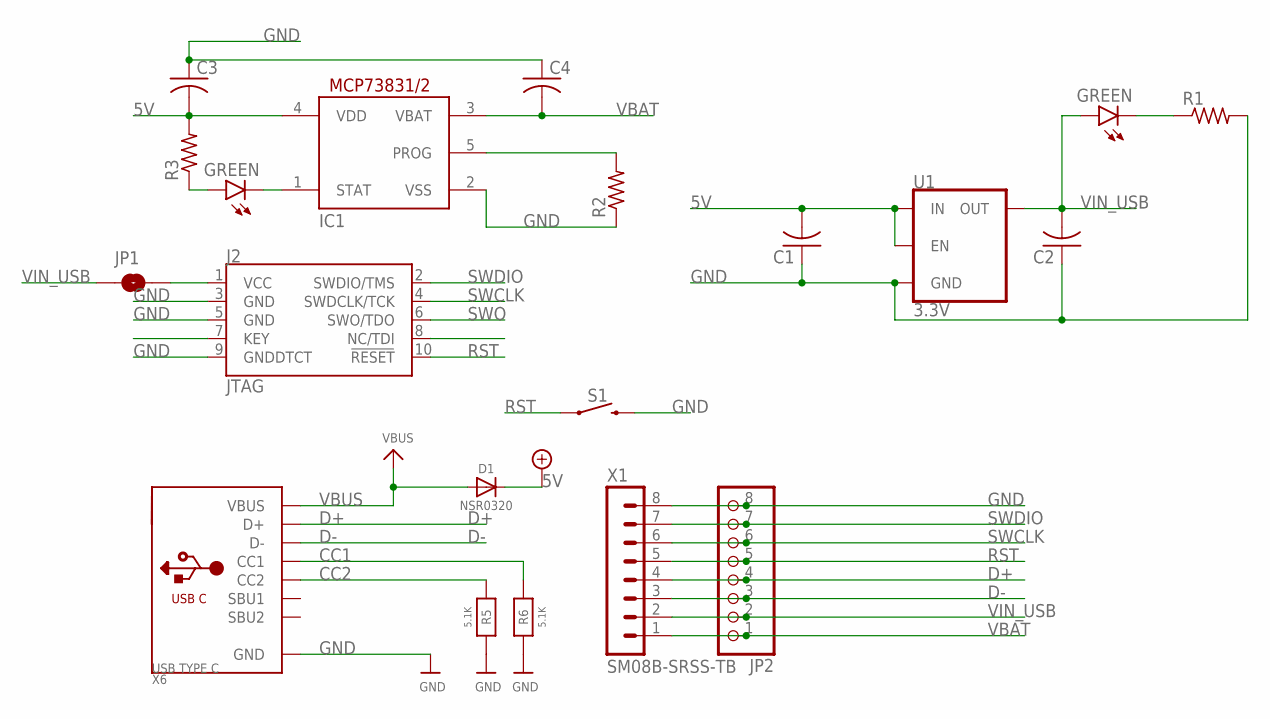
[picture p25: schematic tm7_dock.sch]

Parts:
C1, C2, C3, C4: C-USC0603; C0603
D1: NSR0320; SOD-323_MINI
D2, D3: GREEN; LED-1206
IC1: MCP73831/OT; SOT23-5L
J2: JTAG; 2X5-SMD-1.27MM
JP1: JUMPER-SMT_2_NO_NO-SILK; SMT-JUMPER_2_NO_NO-SILK
JP2: PINHD-1X8LOCK; 1X08-LOCK
R1, R2, R3: R-US_R0603; R0603
R5, R6: 5.1K; _0402NO
S1: MOMENTARY-SWITCH-SPST-SMD-5.2MM-TALL; TACTILE_SWITCH_SMD_5.2MM
U1: 3.3V; SOT23-5
X1: SM08B-SRSS-TB
X6: USB TYPE C; USB_C_CUSB31-CFM2AX-01-X

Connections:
5V: C1.2, C3.2, D1.C, IC1.4 (VDD), R3.2, U1.1 (IN), U1.3 (EN)
CC1: R6.2, X6.A5 (CC1)
CC2: R5.2, X6.B5 (CC2)
D+: JP2.4, X1.4, X6.A6 (D+), X6.B6 (D+)
D-: JP2.3, X1.3, X6.A7 (D-), X6.B7 (D-)
GND: C1.1, C2.1, C3.1, C4.1, IC1.2 (VSS), J2.3 (GND), J2.5 (GND), J2.9 (GNDDTCT), JP2.8, R1.2, R2.1, R5.1, R6.1, S1.3 (2), U1.2 (GND), X1.8, X6.A1B12 (GND), X6.B1A12 (GND)
unnamed: D2.C, R1.1
unnamed: IC1.5 (PROG), R2.2
unnamed: D3.C, IC1.1 (STAT)
unnamed: D3.A, R3.1
unnamed: J2.1 (VCC), JP1.2
RST: J2.10 (!RESET), JP2.5, S1.1, X1.5
SWCLK: J2.4 (SWDCLK/TCK), JP2.6, X1.6
SWDIO: J2.2 (SWDIO/TMS), JP2.7, X1.7
SWO: J2.6 (SWO/TDO)
VBAT: C4.2, IC1.3 (VBAT), JP2.1, X1.1
VBUS: D1.A, X6.A4B9 (VBUS), X6.B4A9 (VBUS)
VIN_USB: C2.2, D2.A, JP1.1, JP2.2, U1.5 (OUT), X1.2

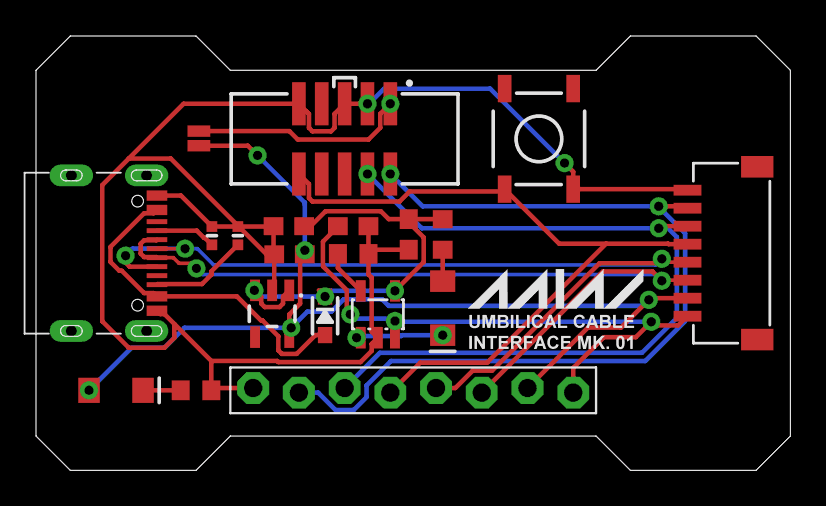
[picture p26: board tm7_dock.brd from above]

Board: 2 copper layers, 41.9 x 24.1 mm, 20 parts (0 on the bottom side), 17 nets.

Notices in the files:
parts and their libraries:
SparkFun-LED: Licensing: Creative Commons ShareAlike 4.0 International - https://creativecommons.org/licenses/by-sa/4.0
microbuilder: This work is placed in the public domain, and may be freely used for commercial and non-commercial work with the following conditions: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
